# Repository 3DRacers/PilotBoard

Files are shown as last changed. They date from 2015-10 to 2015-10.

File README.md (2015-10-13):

# 3DRacers PilotBoard
The first 3D Printed Racing Game, Smartphone-driven and Arduino-compatible

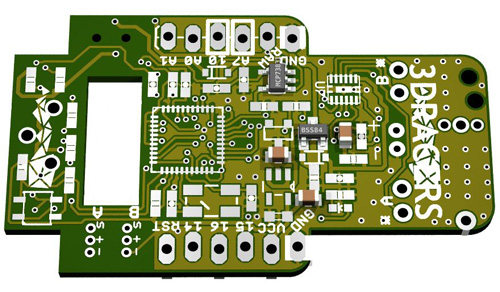
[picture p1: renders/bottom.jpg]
Bottom view
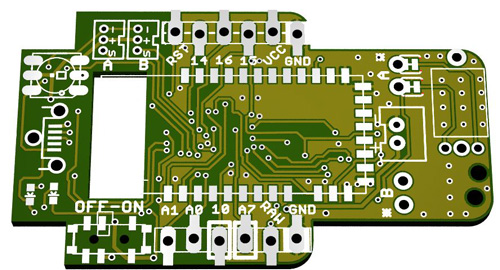
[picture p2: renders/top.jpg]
Top view
 

## The Game

- Race with your friends (up to 1000 players)
- Drive with the Android/Iphone app or the 3D printed remote
- Watch real time score boards and lap times: each car has a sensor that detect specially designed gates.
- Re-program the Arduino core inside each car to unlock new features from the community

More info on: [3DRacers website]

Follow us on Twitter: [@3dracers] and on our community [forum].

Author: Marco D'Alia [@madarco]

## The Arduino code

If you purchased a 3Racers Pilot, you'll find it already programmed with the standard RacerOS code (Arduino-compatible).

However, if you created your own 3DRacers Pilot variation, or you want to modify the Arduino code, go to the

[Lib3DRacers repository] and download the code from there.

# The proto shield

3DRacers Pilot boards support shields, like a standard Arduino. The proto shield is the simpliest shield, that allows soldering of trought-hole components or connectors, but you can use the Eagle file as a template to create your own shield.

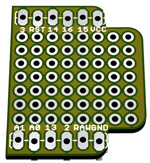
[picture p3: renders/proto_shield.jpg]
Proto Shield Top view
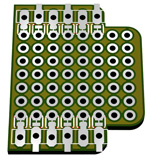
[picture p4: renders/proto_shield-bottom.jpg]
Proto Shield Bottom view
 

### Development

Want to contribute? Great!

Just fork this repo or create an issue.
Also, follow the community [forum]

License
----

Creative Commons Share-Alike 4.0

**Open Hardware, Hell Yeah!**

[//]: # (These are reference links used in the body of this note and get stripped out when the markdown processor does it's job. There is no need to format nicely because it shouldn't be seen. Thanks SO - http://stackoverflow.com/questions/4823468/store-comments-in-markdown-syntax)

   [forum]: <http://forum.3dracers.com>
   [Lib3DRacers repository]: <https://github.com/3DRacers/Lib3DRacers>
   [3DRacers website]: <http://www.3dracers.com>
   [@madarco]: <http://twitter.com/madarco>
   [@3dracers]: <http://twitter.com/3dracers>

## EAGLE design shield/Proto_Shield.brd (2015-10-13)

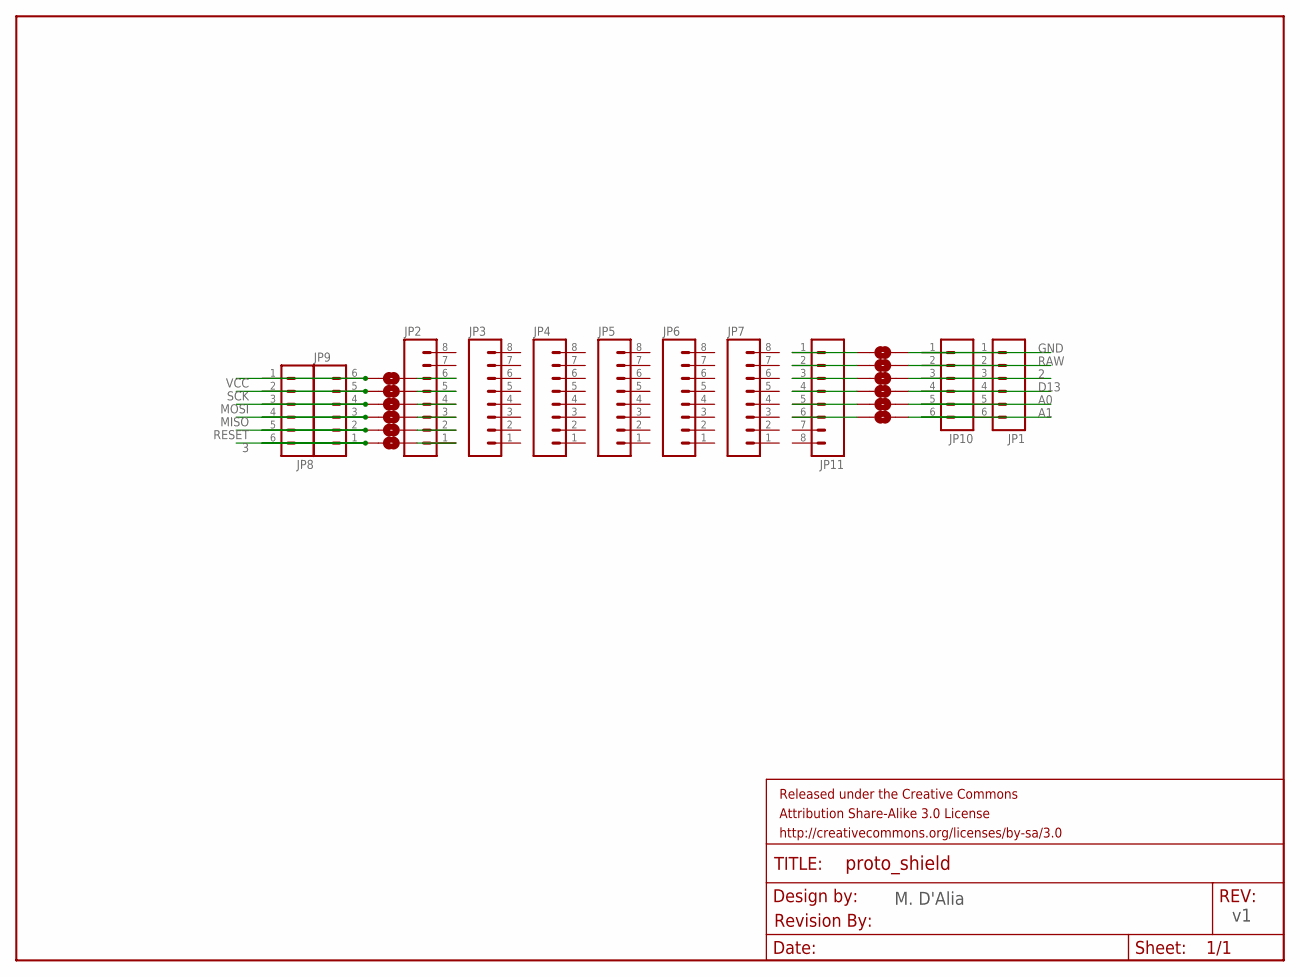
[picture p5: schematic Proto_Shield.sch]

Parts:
FRAME1: FRAME-LETTER; CREATIVE_COMMONS
JP1: M06SMD-STRAIGHT; 1X06_SMD_STRAIGHT
JP2, JP3, JP4, JP5, JP6, JP7, JP11: M08NO_SILK; 1X08_NO_SILK
JP8: M06SMD-STRAIGHT-ALT-NOSILK; 1X06_SMD_STRAIGHT_ALT_NOSILK
JP9, JP10: M06LOCK_LONGPADS; 1X06_LOCK_LONGPADS
SJ1, SJ2, SJ3, SJ4, SJ5, SJ6, SJ7, SJ8, SJ9, SJ10, SJ11, SJ12: SOLDERJUMPERTRACE; SJ_2S-TRACE
U$5: REVISION

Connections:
2: JP1.3, JP10.3, SJ4.1
3: JP8.6, JP9.1, SJ12.2
A0: JP1.5, JP10.5, SJ2.1
A1: JP1.6, JP10.6, SJ1.1
D13: JP1.4, JP10.4, SJ3.1
GND: JP1.1, JP10.1, SJ6.1
MISO: JP8.4, JP9.3, SJ10.2
MOSI: JP8.3, JP9.4, SJ9.2
unnamed: JP11.6, SJ1.2
unnamed: JP11.5, SJ2.2
unnamed: JP11.4, SJ3.2
unnamed: JP11.3, SJ4.2
unnamed: JP11.2, SJ5.2
unnamed: JP11.1, SJ6.2
unnamed: JP2.6, SJ7.1
unnamed: JP2.5, SJ8.1
unnamed: JP2.4, SJ9.1
unnamed: JP2.3, SJ10.1
unnamed: JP2.2, SJ11.1
unnamed: JP2.1, SJ12.1
RAW: JP1.2, JP10.2, SJ5.1
RESET: JP8.5, JP9.2, SJ11.2
SCK: JP8.2, JP9.5, SJ8.2
VCC: JP8.1, JP9.6, SJ7.2

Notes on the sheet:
M. D'Alia

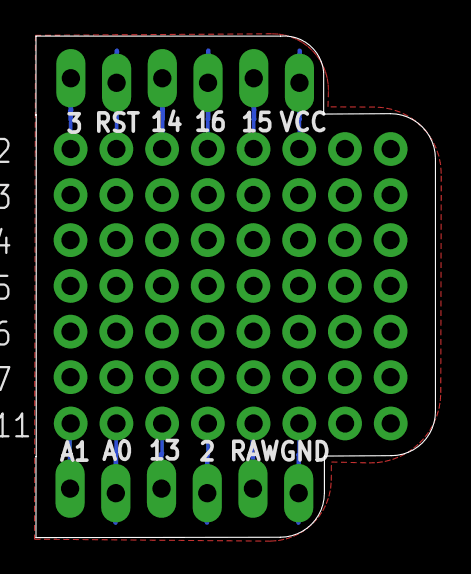
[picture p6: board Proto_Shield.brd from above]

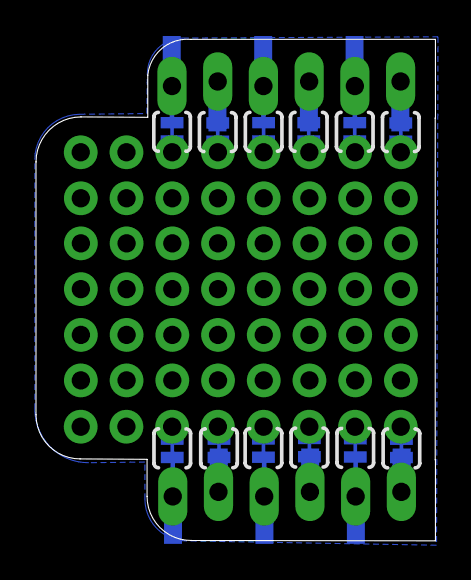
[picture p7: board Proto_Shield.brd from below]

Board: 2 copper layers, 22.2 x 27.9 mm, 25 parts (14 on the bottom side), 24 nets.

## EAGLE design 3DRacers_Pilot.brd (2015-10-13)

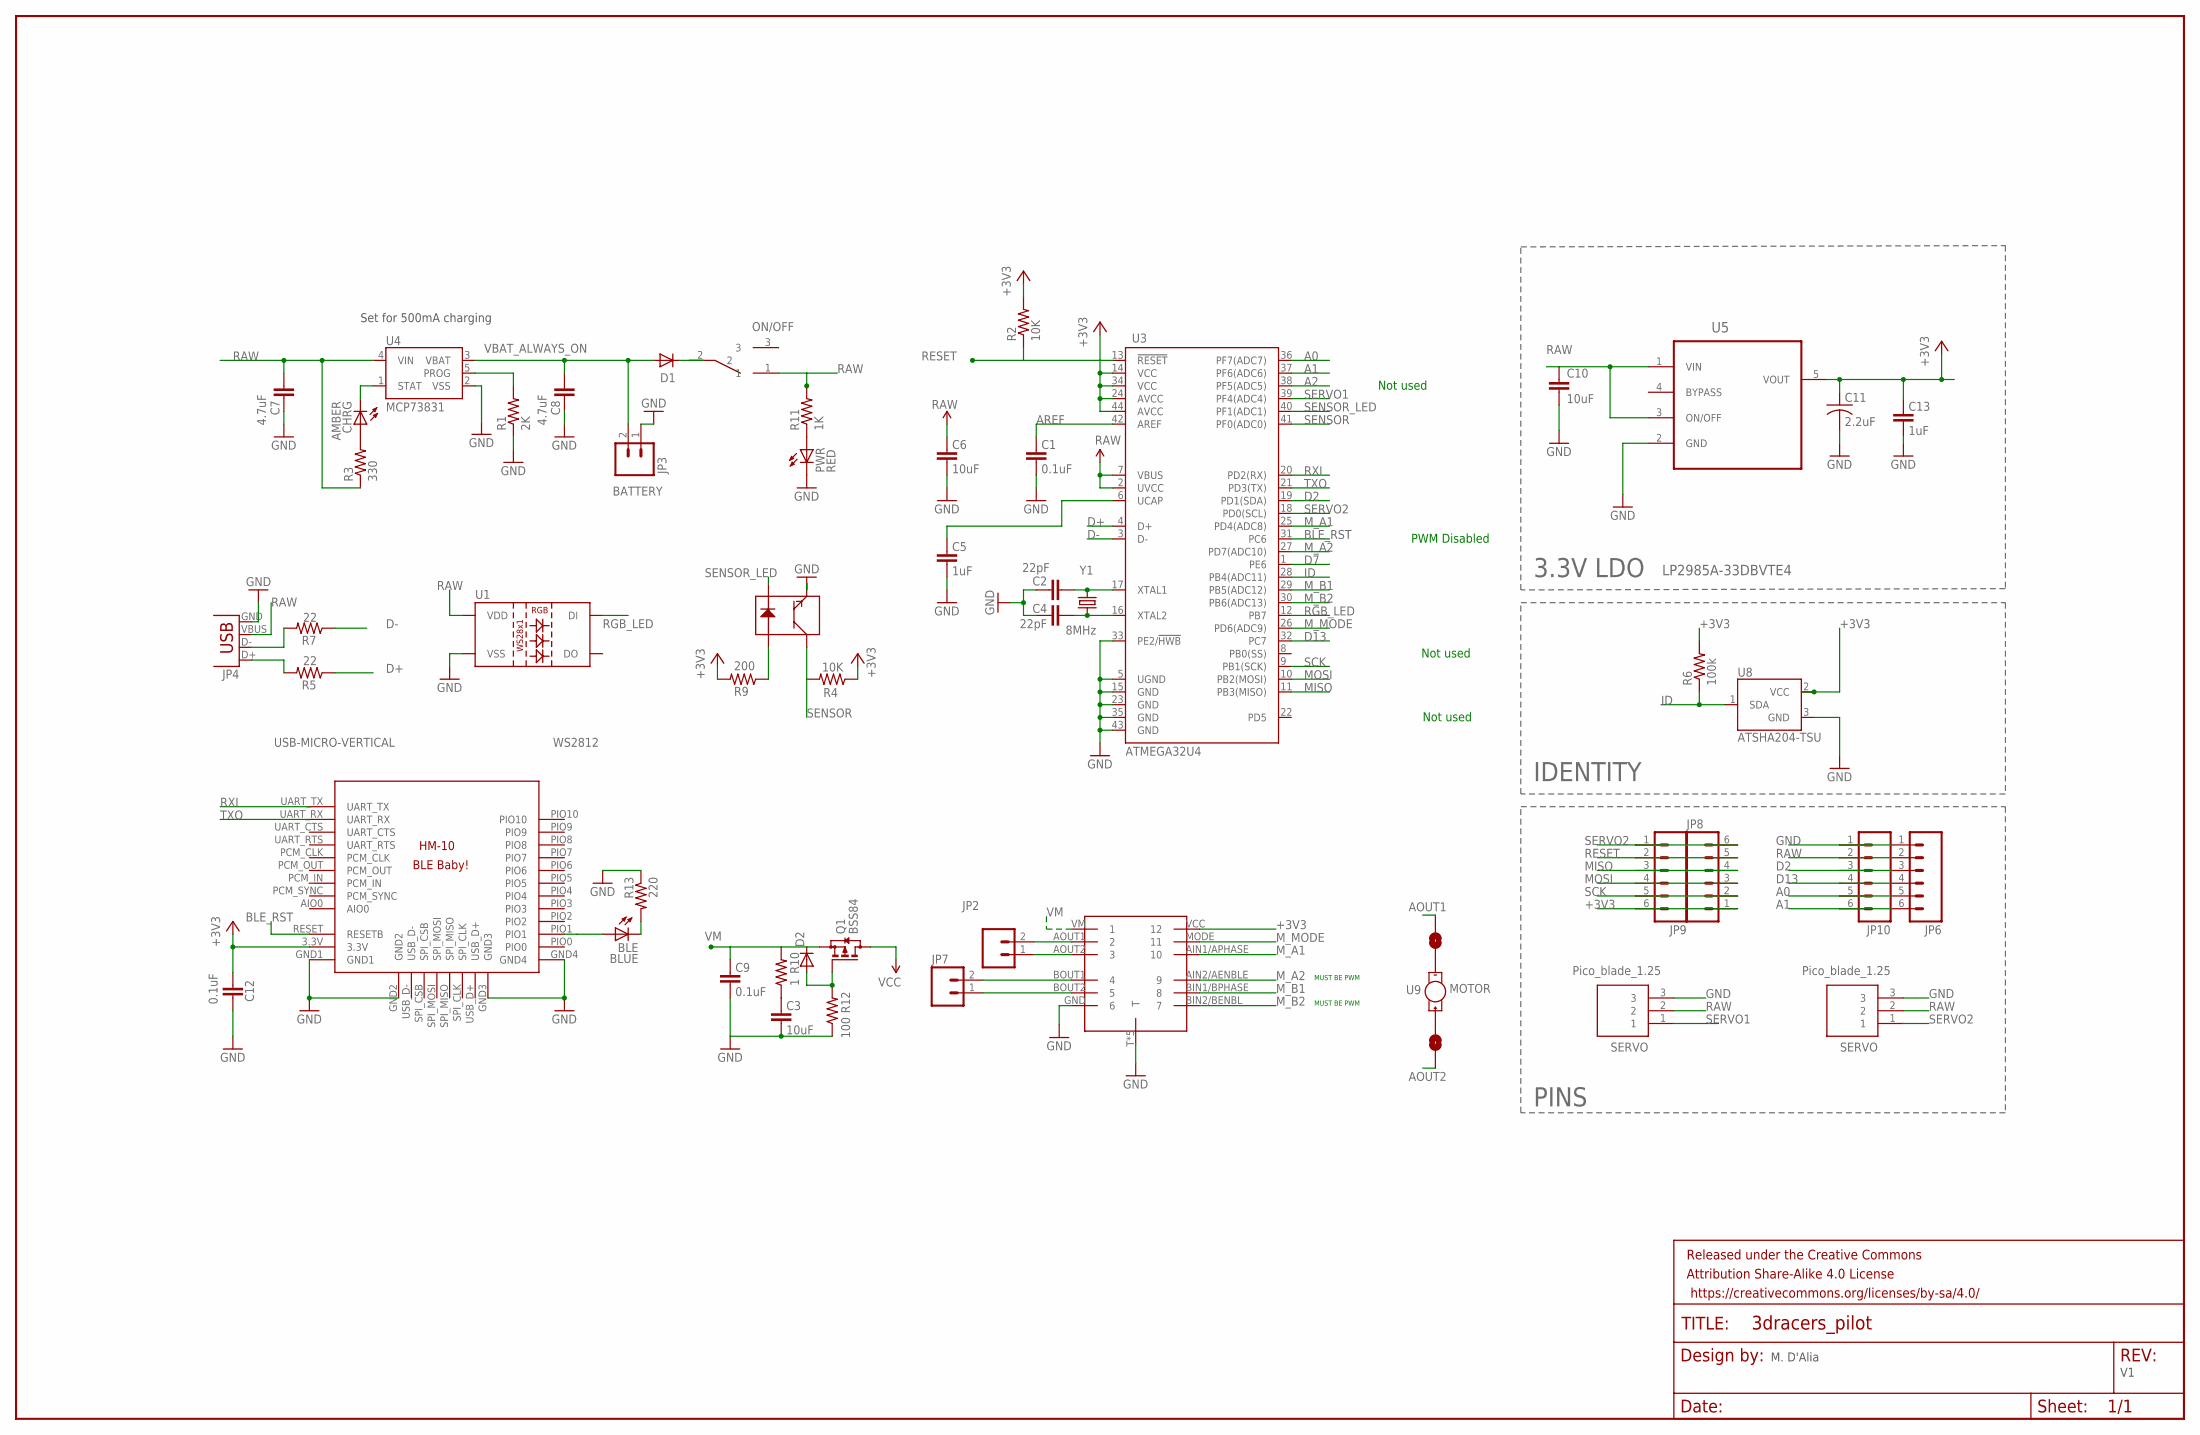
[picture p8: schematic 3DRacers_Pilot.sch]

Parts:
BLE: BLUE; LED-0603
C1, C9, C12: 0.1uF; 0603-CAP
C2, C4: 22pF; 0603-CAP
C3: 10uF; 0805
C5: 1uF; 0603-CAP
C6: 10uF; 0603-CAP
C7, C8: 4.7uF; 0603-CAP
C10: 10uF; 0805; MPN 06036D105KAT2A
C11: 2.2uF; C0603K; MPN 0603YD225MAT2A
C13: 1uF; 0805
CHRG: AMBER; LED-0603
D1, D2: DIODESOD; SOD-323
FRAME2: FRAME-LEDGER; CREATIVE_COMMONS
JP2, JP7: M021X02_NO_SILK; 1X02_NO_SILK
JP3: M02JST-PTH-VERT; JST-2-PTH-VERT
JP4: USB-MICRO-VERTICAL
JP6: M06SMD-STRAIGHT; 1X06_SMD_STRAIGHT
JP8: M06SMD-STRAIGHT-ALT-NOSILK; 1X06_SMD_STRAIGHT_ALT_NOSILK
JP9, JP10: M06LOCK_LONGPADS; 1X06_LOCK_LONGPADS
K2, K3: PICO_BLADE_1.25
PWR: RED; LED-0603
Q1: BSS84; SOT23
R1: 2K; 0603-RES
R2, R4: 10K; 0603-RES
R3: 330; 0603-RES
R5, R7: 22; 0603-RES
R6: 100k; 0603-RES
R9: 200; 0603-RES
R10: 1; 0603-RES
R11: 1K; 0603-RES
R12: 100; 0603-RES
R13: 220; 0603-RES; MPN 0.87.0022.0
SJ1, SJ2: SOLDERJUMPERTRACE; SJ_2S-TRACE
U1: WS2812; LED-TRICOLOR-5050-IC
U3: ATMEGA32U4; QFN-44-NOPAD_1:1-OUTFAKES
U4: MCP73831; SOT23-5
U5: LP2985A-33DBVTE4; SOT95P280X145-5N
U6: QRE1113
U7: DRC8835; DRV8835
U8: ATSHA204-TSU; SOT23-3
U9: MOTOR; MOTOR-6MM-THT
U$2: BLE-HM-10-3DRMODIFIED-FOR-3DRACERS; BLE-HM-10-3DR
U$3: SWITCH; 3DRACERS_SWITCH
Y1: 8MHz; CRYSTAL-SMD-5X3

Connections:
+3V3: C11.1, C12.1, C13.2, JP8.1, JP9.6, R2.2, R4.1, R6.2, R9.2, U3.14 (VCC), U3.24 (AVCC), U3.34 (VCC), U3.44 (AVCC), U5.5 (VOUT), U7.VCC (12), U8.2 (VCC), U$2.3.3V
A0: JP6.5, JP10.5, U3.36 (PF7(ADC7))
A1: JP6.6, JP10.6, U3.37 (PF6(ADC6))
A2: U3.38 (PF5(ADC5))
AOUT1: JP7.2, SJ1.2, U7.BOUT1 (4)
AOUT2: JP7.1, SJ2.2, U7.BOUT2 (5)
AREF: C1.2, U3.42 (AREF)
BLE_CON: BLE.A, U$2.PIO1
BLE_RST: U3.31 (PC6), U$2.RESET (RESETB)
BOUT1: JP2.2, U7.AOUT1 (2)
D2: JP6.3, JP10.3, U3.19 (PD1(SDA))
D7: U3.1 (PE6)
D13: JP6.4, JP10.4, U3.32 (PC7)
D+: R5.1, U3.4 (D+)
D-: R7.1, U3.3 (D-)
GND: C1.1, C2.2, C3.1, C4.2, C5.1, C6.1, C7.2, C8.2, C9.1, C10.2, C11.2, C12.2, C13.1, JP3.1, JP4.GND, JP6.1, JP10.1, K2.3, K3.3, PWR.C, R1.1, R12.1, R13.1, U1.6 (VSS), U3.5 (UGND), U3.15 (GND), U3.23 (GND), U3.33 (PE2/!HWB), U3.35 (GND), U3.43 (GND), U4.2 (VSS), U5.2 (GND), U6.4 (E), U7.GND (6), U7.T, U7.T@12 (T), U7.T@15 (T), U7.T@16 (T), U7.T@17 (T), U8.3 (GND), U$2.GND1, U$2.GND2, U$2.GND3, U$2.GND4
ID: R6.1, U3.28 (PB4(ADC11)), U8.1 (SDA)
MISO: JP8.4, JP9.3, U3.11 (PB3(MISO))
MOSI: JP8.3, JP9.4, U3.10 (PB2(MOSI))
M_A1: U3.25 (PD4(ADC8)), U7.AIN1/APHASE (10)
M_A2: U3.27 (PD7(ADC10)), U7.AIN2/AENBLE (9)
M_B1: U3.29 (PB5(ADC12)), U7.BIN1/BPHASE (8)
M_B2: U3.30 (PB6(ADC13)), U7.BIN2/BENBL (7)
M_MODE: U3.26 (PD6(ADC9)), U7.MODE (11)
unnamed: C4.1, U3.16 (XTAL2), Y1.1
unnamed: C2.1, U3.17 (XTAL1), Y1.3 (2)
unnamed: JP4.D-, R7.2
unnamed: C5.2, U3.6 (UCAP)
unnamed: R9.1, U6.1 (A)
unnamed: SJ1.1, U9.-
unnamed: JP4.D+, R5.2
unnamed: CHRG.A, R3.2
unnamed: JP2.1, U7.AOUT2 (3)
unnamed: D2.2 (A), Q1.1 (G), R12.2
unnamed: C3.2, R10.1
unnamed: SJ2.1, U9.+
unnamed: D1.1 (C), U$3.2
unnamed: BLE.C, R13.2
unnamed: PWR.A, R11.1
PROG: R1.2, U4.5 (PROG)
RAW: C6.2, C7.1, C10.1, JP4.VBUS, JP6.2, JP10.2, K2.2, K3.2, Q1.3 (D), R3.1, R11.2, U1.3 (VDD), U1.5 (VDD), U3.2 (UVCC), U3.7 (VBUS), U4.4 (VIN), U5.1 (VIN), U5.3 (ON/OFF), U$3.1
RESET: JP8.5, JP9.2, R2.1, U3.13 (!RESET)
RGB_LED: U1.2 (DI), U3.12 (PB7)
RXI: U3.20 (PD2(RX)), U$2.UART_TX
SCK: JP8.2, JP9.5, U3.9 (PB1(SCK))
SENSOR: R4.2, U3.41 (PF0(ADC0)), U6.3 (C)
SENSOR_LED: U3.40 (PF1(ADC1)), U6.2 (K)
SERVO1: K2.1, U3.39 (PF4(ADC4))
SERVO2: JP8.6, JP9.1, K3.1, U3.18 (PD0(SCL))
STAT: CHRG.C, U4.1 (STAT)
TXO: U3.21 (PD3(TX)), U$2.UART_RX
VBAT_ALWAYS_ON: C8.1, D1.2 (A), JP3.2, U4.3 (VBAT)
VM: C9.2, D2.1 (C), Q1.2 (S), R10.2, U7.VM (1)

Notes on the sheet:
Set for 500mA charging
MUST BE PWM
ON/OFF
BATTERY
3.3V LDO
PINS
IDENTITY
Not used
PWM Disabled
M. D'Alia

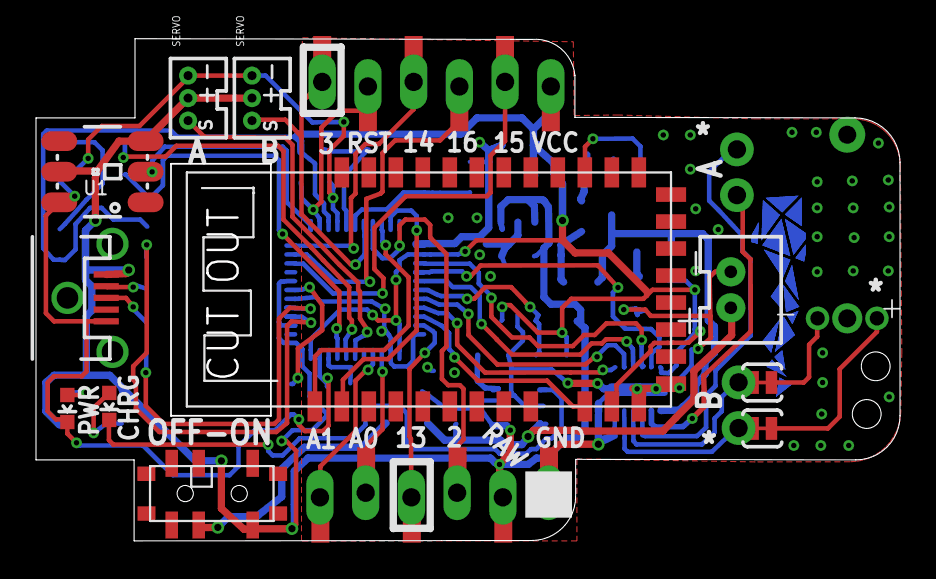
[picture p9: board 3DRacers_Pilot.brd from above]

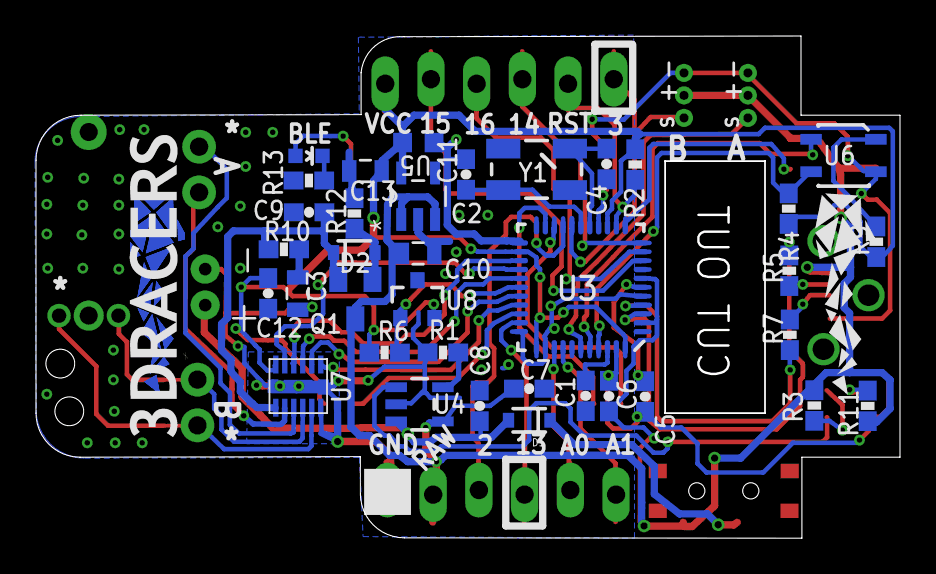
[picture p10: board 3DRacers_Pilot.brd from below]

Board: 2 copper layers, 48.0 x 27.9 mm, 55 parts (37 on the bottom side), 51 nets.

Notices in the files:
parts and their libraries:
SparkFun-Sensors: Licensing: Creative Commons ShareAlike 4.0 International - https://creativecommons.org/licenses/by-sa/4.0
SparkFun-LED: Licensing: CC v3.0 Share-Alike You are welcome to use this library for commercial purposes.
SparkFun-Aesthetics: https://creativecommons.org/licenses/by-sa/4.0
